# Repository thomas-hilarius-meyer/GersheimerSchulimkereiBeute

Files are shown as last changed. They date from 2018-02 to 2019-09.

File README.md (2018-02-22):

# GersheimerSchulimkereiBeute
Entwicklung eines Bienenkastens für die pädagogisch ausgerichtete Bienenhaltung - LaTeX-Dateien und CAD-Pläne

Es geht um die Entwicklung eines Bienenkastens, der sich in besonderer Weise dazu eignet, das imkern zu lernen:

- Keine schweren Honigzargen heben.
- keine auffliegenden Bienen beim Abheben einer ganzen Etage.
- trotzdem ein ein gängiges Wabenmaß (Zander).
- einfachste Herstellung und
- geringe Kosten.

Mitentwickler herzlich willkommen.

(Zur Bearbeitung der Pläne wird FreeCAD benötigt;
die Texte sind in LATeX erstellt.)

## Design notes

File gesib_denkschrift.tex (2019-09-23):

\documentclass[12pt,a4paper,ngerman]{scrartcl}

\usepackage[ngerman]{babel}
\usepackage[utf8]{inputenc}
\usepackage[T1]{fontenc}
\usepackage{csquotes}
\usepackage{graphicx}
\usepackage{hyperref}

\author{Dr. Thomas Hilarius Meyer\\ \textsf{thomas.hilarius.meyer@gmail.com}}
\title{Die Gersheimer Schulimkerei-Beute (GeSIB)}
\subtitle{Überlegungen zu Konzeption, Bau und Betriebsweise}
\date{Fassung 24. März 2019}

\begin{document}
\maketitle

\begin{abstract}
  Die Gersheimer Schulimkerei-Beute (GeSIB) ist eine Trogbeute für 21 Waben im Zander-Maß.
  Sie eignet sich besonders für den pädagogisch motivierten Umgang mit Bienen, da alle Waben in einer
  Ebene liegen und somit direkt einsehbar und zugänglich sind; im Umgang mit ihr sind
  keine schweren Gewichte zu heben und die Arbeitshöhe bleibt konstant.
  Alle Verfahren der modernen Magazin-Imkerei lassen sich mit der GeSIB durchführen und
  ein späterer Wechsel der Jungimker etwa zu üblichen Magazinbeuten ist problemlos möglich.
\end{abstract}

\section{Gestaltungsprinzipien}

Die Zeit ist reif für einen neuen Bienenkasten,
der speziell auf die Bedürfnisse einer Schulimkerei und ihrer Mitglieder --
besonders in den ersten 1--2 Jahren des Imkern-Lernens -- ausgelegt ist!

Die Mitglieder der Schulimkerei Gersheim haben eine Bienenbeute entwickelt,
die sich ausschließlich diesem Ziel widmet:
die Gersheimer Schulimkerei-Beute (GeSIB).

Nach Abschluss des laufenden Erprobungsbetriebes wird die Herstellung der GeSIB die Angebotspalette unserer
Schülerfirma entscheidend erweitern;
gleichzeitig stehen die Baupläne der Öffentlichkeit zur Verfügung.%
\footnote{\url{http:\\\\github.com\\thomas-hilarius-meyer\\GersheimerSchulimkereiBeute}}

\subsection{Vorüberlegungen / Anforderungen}

Was müsste ein Schulbienenkasten besser können als etablierter und bewährter Bienenkasten,
z.\,B. die \enquote{Liebig-Beute}?

\begin{enumerate}
\item Die Imkerneulinge sollen keine Zargen abheben müssen, denn dies bedeutet\ldots
  \begin{itemize}
  \item eine Frage der Kraft,
  \item ist eine psychologische Hemmschwelle
  \item  und eine Störung der Bienen.
  \end{itemize}
\item Alle Teile des Bienenstocks sollen gleichzeitig sichtbar sein (von oben, auf einen Blick),
\item das Wabenmaß soll das weit verbreitete Zandermaß sein,
  um später leichter auf Magazinbeuten umsteigen zu können (eine Beute, aus der man \enquote{herauswächst}...),
\item die Betriebsweise soll sehr nahe an der Magazinimkerei liegen (imkern lernen) und
\item der Bau soll zu einem geringen Preis und
\item mit wenig Aufwand möglich sein.
\end{enumerate}

In Kauf genommene Nachteile sind weitgehend irrelevant für den speziellen Zweck der \enquote{pädagogischen} Bienenbeute:

\begin{itemize}
\item \enquote{Unwirtschaftliches} Arbeiten (\enquote{wabenweise} statt \enquote{zargenweise}) -- es geht nicht um Erwerbsbienenhaltung,
  sondern um pädagogisch orientiertes Imkern.
\item Schwieriges Wandern wegen des hohen Beuten-Gewichts -- eine Schulimkerei ist erfahrungsgemäß immer eine Standimkerei.
\end{itemize}

\subsection{Konkrete Designentscheidungen}

Folgende Konstruktionsentscheidungen sind für den Entwurf maßgeblich:

\begin{itemize}
\item Zander-Rähmchen als verbreitetstes Rähmchenmaß,
\item gleiches Maß im Brut- und Honigraum,
\item Möglichkeit eines vertikalen Königinnenabsperrgitters und
\item einer vertikalen Bienenflucht,
\item extrem leichter Zusammenbau aus wenigen, einfachen Teilen.
\end{itemize}

\section{Bisherige Ansätze}

Welche Bienenkästen mit grundsätzlich ähnlicher Konstruktion (Waben auf einer Ebene)
gibt es schon und warum sind diese für die speziellen Zwecke einer Schulimkerei
nicht oder nicht optimal geeignet?

\begin{description}
\item[Hohenheimer Einfachbeute] ideales System für \enquote{erwachsene} Imker;
  doch Nachteil: schweres Heben, Scheu des Zargen-Abhebens\ldots
\item[Golzbeute] komplizierter Aufbau, teuer, spezielles Wabenmaß (Kuntzsch hoch), keine Bienenflucht.
\item[Mellifera Einraumbeute] spezielles Wabenmaß, kein Abspergitter und keine Bienenflucht möglich.
\item[Top-Bar-Hive] Umstieg auf Magazin-Imkerei sehr kompliziert.
\item[Bienenkiste] extrem unergonomisch; Stabilbau verhindert Wabenkontrolle.
\item[Kunesa-Beute] extrem hoher Preis; Werkstoff Kunststoff erlaubt kein handwerkliches Arbeiten
  (Reparaturen etc.) und auch keinen Selbstbau.
\item[BienenBox] Seltenes Wabenformat (Format Kuntzsch hoch) macht den Umstieg auf Magazinbeuten schwierig
  (www.bienenbox.de)
\item[Citybox (Fa. Holtermann)] hoher Preis, teilweise überspezielle Features
\item[Alpentrogbeute (V. Weber)] komplizierter Aufbau, schwer zu bekommen, Honigräume werden aufgesetzt --
  dadurch gehen gerade die Vorzüge der Trogbeute verloren!
\end{description}

\section{Bau}

\minisec{Planskizze}

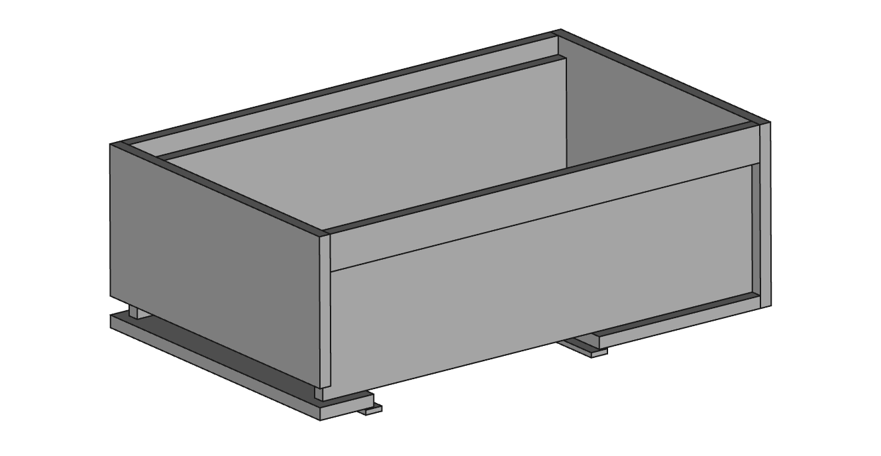
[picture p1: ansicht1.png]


\begin{center}
  [Achtung! Älterer Planungsstand, Skizze nicht maßstabsgerecht!
  Vgl. ggf. separate FreeCAD-Datei bzw. PDF-Pläne für konstruktive Details.]
\end{center}

\minisec{Teileliste}

\begin{center}
\begin{tabular}{lll}
  Bezeichnung &                       Maße [in mm] &          Anzahl \\
  \hline
  Leimholzplatten 25mm: \\
  Seitenbrett links + rechts &        800 x 270 &             2 \\
  Seitl. Griffbrett links + rechts &  800 x 60 &              2 \\
  Stirnbrett vorne &                  540 x 275 &             1 \\
  Rückwand &                          540 x 320 &             1 \\
  Bodenbrett hinten &                 540 x 360 &             1 \\
  Bodenbrett vorne &                  540 x 100 &             1 \\
  \hline
  Sperrholz 8mm o.\,ä.: \\
  Schubleisten &                      540 x 60 &              2 \\
  \hline
  Dämmmaterial (z.\,B. MDF): \\
  Innendeckel (Dämmmaterial) &        850 x 540 &             1 \\
  \hline
\end{tabular}
\end{center}

Alternativ zum MDF-Innendeckel lassen sich auch zwei Standard-Liebig-Innendeckel nebeneinander verwenden.

\minisec{Zusatzteile}

\begin{center}
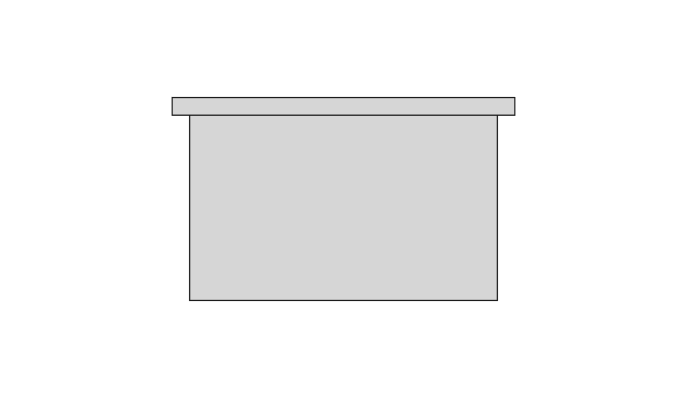
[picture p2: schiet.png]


\begin{tabular}{ll}
  Bezeichnung &                       Maße [in mm] \\
  \hline
  Trägerleiste &                      490 x 25 x 10 \\
  Schiet-Brett &                      440 x 295 x 10 \\
  \hline
\end{tabular}
\end{center}

Zum Betrieb werden drei Varianten eines vertikalen Trennschieds benötigt:

\begin{itemize}
\item das Trennschied selbst, um v.\,a. im Winter den Innenraum der Beute zu begrenzen,
\item ein vertikales Königinnenabsperrgitter und
\item eine vertikale Bienenflucht.
\end{itemize}

\minisec{Zusätzliches Material}

\begin{itemize}
\item Schrauben 5x60mm
\item wasserfester Leim
\item Anstrich (Leinölfirnis)
\end{itemize}

\section{Offene Fragen}

Folgende Punkte sollen während des derzeit (2019/20) laufenden ersten Jahres Erprobungsbetrieb untersucht werden,
um ggf. die Konstruktion noch zu verändern:

\begin{enumerate}
%\item Boden: Öffnungen wegen Belüftung und besserer Varroabeobachtung? Oder reicht die Zugänglichkeit über das Flugloch?
%  (Stabilität der Konstruktion)
\item Notwendigkeit des Abspergitters:
  evtl. unnötig wg. des natürlichen Triebs der Königin, das Brutnest fluglochnah zusammenzuhalten?
\item Effektivität der vertikalen Bienenflucht?
\end{enumerate}

\section{Betriebsweise}

Die imkerliche Betriebsweise mit der GSIB ähnelt grundsätzlich sehr stark den Verfahrensweisen in der Magazin-Imkerei (Liebig 2011):

\subsection{Varroa: Winterbehandlung mit Oxalsäure}

Die Bekämpfung der Varroamilbe im brutfreien Zustand im Winter kann problemlos sowohl durch Träufeln von oben als auch durch Verdampfen von unten erfolgen.
Durch die flache Bauweise wird der Bienensitz nur minimal gestört.

%(Idee: Einblasloch im Fluglochstück? Entwicklung eines Verdampfers auf Basis eines Gasbrenners?)

\subsection{Ablegerbildung}

Die Vermehrung der Völkerzahl durch die Bildung von Ablegern erfolgt
entweder durch Bildung in der GeSIB (mit Fluglochverkleinerung und Volumenbegrenzungsschied)
oder in normalem Zander-Ablegerkasten (gleiches Wabenmaß).

\subsection{Honigernte}

Durch die Benutzung des vertikalen Absperrgitters sowie
der vertikale Bienenflucht
gestaltet sich die Honigernte einfach und ohne massiv mit den Bienen in Kontakt zu kommen.

\subsection{Varroa: Sommerbehandlung mit Ameisensäure}

Die Sommerbehandlung der Varroamilbe erfolgt am einfachsten durch Einsatz der bekannten
Nassenheider Professional-Verdunster im bisherigen Honigraum.

Die Bodenöffnung lässt sich mit Bodenschiebern der standardisierten Liebig-Beute verschließen.

\subsection{Einfütterung}

Der Futtereimer findet ebenfalls problemlos im Honigraum Platz.

\subsection{Überwinterung}

Zur Erhaltung des Stockklimas ist der Einsatz des Trennschiedes während des Winters notwendig, das eng an die besetzten Waben herangerückt wird.
Die thermischen Eigenschaften der GeSIB sind dann nicht ungünstiger als bei einer Magazinbeute.

\section{Chronologie}

\begin{description}
\item[Herbst 2017] erste Vorüberlegungen
\item[Januar/Februar 2018] Planskizze
\item[Winter 2018/19] Bau eines Prototypen; Überarbeitung der Maße
\item[Imkersaison 2019/20] Erprobungsbetrieb in Gersheim
\end{description}

\section{Literaturhinweise}

\begin{enumerate}
\item Johannes Otto Hüsing u. Joachim Nitschmann (Hgg.), Lexikon der Bienenkunde, München 1987; s.\,v.
  \enquote{Trogbeute} u.
  \enquote{Entwicklung der Bienenwohnungen.}
\item Gerhard Liebig, Einfach imkern, (3. Aufl.) 2011.
\item Friedrich Pohl (Hg.), Bienenkiste, Korb und Einfachbeuten. Naturnah und erfolgreich imkern, Stuttgart 2013.
\item Johannes Weber, Bienen halten mit der BienenBox, Stuttgart 2016.
\item Vinzenz Weber, Leichter imkern mit Trogbeuten, München (2. Aufl.) 1990.
\end{enumerate}

\section{Ressourcen}

\url{http:\\\\schulimkerei.blogspot.com}

\url{http:\\\\github.com\\thomas-hilarius-meyer\\GersheimerSchulimkereiBeute}

\end{document}

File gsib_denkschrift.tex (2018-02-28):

\documentclass[12pt,a4paper,ngerman]{scrartcl}

\usepackage[ngerman]{babel}
\usepackage[utf8]{inputenc}
\usepackage[T1]{fontenc}
\usepackage{csquotes}
\usepackage{graphicx}

\author{Thomas Hilarius Meyer\\ \textsf{thomas.hilarius.meyer@gmail.com}}
\title{Die Gersheimer Schulimkerei-Beute (GSIB)}
\subtitle{Überlegungen zu Konzeption, Bau und Betriebsweise}

\begin{document}
	\maketitle

\begin{abstract}
	Die Gersheimer Schulimkerei-Beute (GSIB) ist eine Trogbeute für 24 Zander-Rähmchen.
	Sie eignet sich besonders für den pädagogischen Umgang mit Bienen, da alle Waben in einer
	Ebene liegen und somit direkt einsehbar und zugänglich sind; im Umgang mit ihr sind
	keine schweren Gewichte zu heben und die Arbeitshöhe bleibt konstant.
	Alle Verfahren der modernen Magazin-Imkerei lassen sich mit der GSIB durchführen und
	ein späterer Wechsel der Jungimker etwa zur Liebigbeute ist problemlos möglich.
\end{abstract}

\section{Gestaltungsprinzipien}

Die Zeit ist reif für einen neuen Bienenkasten, der speziell auf die Bedürfnisse einer Schulimkerei und ihrer Mitglieder --
besonders in den ersten 1--2 Jahren des Imkern-Lernens -- ausgelegt ist!

Die Mitglieder der Schulimkerei Gersheim haben eine Bienenbeute entwickelt, die sich ausschließlich diesem Ziel widmet:
die Gersheimer Schulimkerei-Beute (GSIB).

Nach einem angemessenen Erprobungsbetrieb könnte die Herstellung der GSIB die Angebotspalette unserer Schüllerfirma
entscheidend erweitern.

\subsection{Vorüberlegungen / Anforderungen}

Was müsste ein Schulbienenkasten besser können als die Liebig-Beute?

\begin{enumerate}
\item Die Imkerneulinge sollen keine Zargen abheben müssen, denn dies bedeutet...
  \begin{itemize}
  \item eine Frage der Kraft,
  \item ist eine psychologische Hemmschwelle
  \item  und eine Störung der Bienen.
  \end{itemize}
\item Alle Teile des Bienenstocks sollen gleichzeitig sichtbar sein (von oben, auf einen Blick),
\item das Wabenmaß soll das weit verbreitete Zandermaß sein,
  um später leichter auf Magazinbeuten umsteigen zu können (eine Beute, aus der man \enquote{herauswächst}...),
\item die Betriebsweise soll sehr nahe an der Magazinimkerei liegen (imkern lernen) und
\item der Bau soll zu einem geringen Preis und
\item mit wenig Aufwand möglich sein.
\end{enumerate}

In Kauf genommene Nachteile sind weitgehend irrelevant für den speziellen Zweck der \enquote{pädagogischen} Bienenbeute:

\begin{itemize}
\item \enquote{Unwirtschaftliches} Arbeiten (\enquote{wabenweise} statt \enquote{zargenweise}) -- es geht nicht um Erwerbsbienenhaltung,
  sondern um pädagogisch orientiertes Imkern.
\item Schwieriges Wandern wegen des hohen Beuten-Gewichts -- eine Schulimkerei ist erfahrungsgemäß immer eine Standimkerei.
\end{itemize}

\subsection{Konkrete Designentscheidungen}

Folgende Konstruktionsentscheidungen sind für den Entwurf maßgeblich:

\begin{itemize}
\item Zander-Rähmchen als verbreitetstes Rähmchenmaß,
\item gleiches Maß im Brut- und Honigraum,
\item vertikales Königinnenabsperrgitter möglich,
\item Möglichkeit einer vertikalen Bienenflucht,
\item extrem leichter Zusammenbau aus wenigen, einfachen Teilen.
\end{itemize}

\section{Bisherige Ansätze}

Welche Bienenkästen mit grundsätzlich ähnlicher Konstruktion (Waben auf einer Ebene) gibt es schon und warum sind diese
für die speziellen Zwecke einer Schulimkerei nicht oder nicht optimal geeignet?

\begin{description}
\item[Hohenheimer Einfachbeute] ideales System für \enquote{erwachsene} Imker; doch Nachteil: schweres Heben, Scheu des Zargen-Abhebens...
\item[Golzbeute] komplizierter Aufbau, teuer, spezielles Wabenmaß (Kuntzsch hoch), keine Bienenflucht.
\item[Mellifera Einraumbeute] spezielles Wabenmaß, kein Abspergitter und keine Bienenflucht möglich.
\item[Top-Bar-Hive] Umstieg auf Magazin-Imkerei sehr kompliziert.
\item[Bienenkiste] extrem unergonomisch; Stabilbau verhindert Wabenkontrolle.
\item[Kunesa-Beute]
\item[BienenBox] Format Kuntzsch (hoch)  (www.bienenbox.de)
\item[Citybox (Fa. Holtermann)]
\item[Alpentrogbeute (V. Weber)] komplizierter Aufbau, schwer zu bekommen, Honigräume werden aufgesetzt!
\end{description}

\section{Bau}



[vgl. separate FreeCAD-Datei bzw. PDF-Pläne für konstruktive Details.]

\minisec{Teileliste}

\begin{center}
\begin{tabular}{lll}
  Bezeichnung &                       Maße [in mm] &          Anzahl \\
  \hline
  Seitenbrett links + rechts &        800 x 240 &             2 \\
  Seitl. Griffbrett links + rechts &  800 x 60 &              2 \\
  Stirnbrett vorne &                  540 x 240 &             1 \\
  Rückwand &                          540 x 290 &             1 \\
  Bodenbrett hinten &                 540 x 300 &             1 \\
  Bodenbrett vorne &                  540 x 100 &             1 \\
  Schubleisten &                      540 x 30 x 8 &          2 \\
  \hline
  Innendeckel (Dämmmaterial) &        850 x 540 &             1 \\
  \hline
\end{tabular}

[Materialstärke 25mm wenn nicht angegeben.]
\end{center}

\minisec{Zusatzteile}

\begin{itemize}
\item vertikales Königinnenabsperrgitter
\item vertikale Bienenflucht
\end{itemize}

\section{Offene Fragen}

\begin{enumerate}
%\item Boden: Öffnungen wegen Belüftung und besserer Varroabeobachtung? Oder reicht die Zugänglichkeit über das Flugloch?
%  (Stabilität der Konstruktion)
\item Notwendigkeit des Abspergitters: evtl. unnötig wg. des natürlichen Triebs der Königin, das Brutnest fluglochnah zusammenzuhalten?
\end{enumerate}

\section{Betriebsweise}

\subsection{Varroa: Winterbehandlung mit Oxalsäureverdampfer}

(Idee: Einblasloch im Fluglochstück? Entwicklung eines Verdampfers auf Basis eines Gasbrenners?)

\subsection{Ablegerbildung}

Entweder Bildung in der GSB (mit Fluglochverkleinerung und Volumenbegrenzungsschied)
oder in normalem Zander-Ablegerkasten

\subsection{Honigernte}

Benutzung des vertikalen Absperrgitters

vertikale Bienenflucht

\subsection{Varroa: Sommerbehandlung mit Ameisensäure}

Nassenheider Professional im bisherigen Honigraum

\subsection{Einfütterung}

Eimer im Honigraum

\section{Chronologie}

\begin{description}
\item[Herbst 2017] erste Vorüberlegungen
\item[Januar/Februar 2018] Planskizze
\item[Imkersaison 2018] Erprobungsbetrieb in Gersheim
\end{description}

\section{Literaturhinweise}

\begin{enumerate}
\item Gerhard Liebig, Einfach imkern, (3. Aufl.) 2011.
\item Friedrich Pohl (Hg.), Bienenkiste, Korb und Einfachbeuten. Naturnah und erfolgreich imkern, Stuttgart 2013.
\item Johannes Weber, Bienen halten mit der BienenBox, Stuttgart 2016.
\item Vinzenz Weber, Leichter imkern mit Trogbeuten, München (2. Aufl.) 1990.
\end{enumerate}
\end{document}

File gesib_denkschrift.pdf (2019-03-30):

# Die Gersheimer Schulimkerei-Beute (GeSIB)

### Überlegungen zu Konzeption, Bau und Betriebsweise

## Thomas Hilarius Meyer

## thomas.hilarius.meyer@gmail.com

## 1. März 2019

Die Gersheimer Schulimkerei-Beute (GeSIB) ist eine Trogbeute für 21 Waben im Zander-Maß. Sie eignet sich besonders für den pädagogisch motivierten Umgang mit Bienen, da alle Waben in einer Ebene liegen und somit direkt einsehbar und zugänglich sind; im Umgang mit ihr sind keine schweren Gewichte zu heben und die Arbeitshöhe bleibt konstant. Alle Verfahren der modernen Magazin-Imkerei lassen sich mit der GeSIB durchführen und ein späterer Wechsel der Jungimker etwa zu üblichen Magazinbeuten ist problemlos möglich.

## 1 Gestaltungsprinzipien

Die Zeit ist reif für einen neuen Bienenkasten, der speziell auf die Bedürfnisse einer Schulimkerei und ihrer Mitglieder – besonders in den ersten 1–2 Jahren des Imkern-Lernens – ausgelegt ist!
Die Mitglieder der Schulimkerei Gersheim haben eine Bienenbeute entwickelt, die sich ausschließlich diesem Ziel widmet: die Gersheimer Schulimkerei-Beute (GeSIB).
Nach einem angemessenen Erprobungsbetrieb könnte die Herstellung der GeSIB die Angebotspalette unserer Schülerfirma entscheidend erweitern.

### 1.1 Vorüberlegungen / Anforderungen

Was müsste ein Schulbienenkasten besser können als die Liebig-Beute?

1. Die Imkerneulinge sollen keine Zargen abheben müssen, denn dies bedeutet...
- eine Frage der Kraft,
- ist eine psychologische Hemmschwelle

1

- und eine Störung der Bienen.
2. Alle Teile des Bienenstocks sollen gleichzeitig sichtbar sein (von oben, auf einen Blick),
3. das Wabenmaß soll das weit verbreitete Zandermaß sein, um später leichter auf Magazinbeuten umsteigen zu können (eine Beute, aus der man „herauswächst“...),
4. die Betriebsweise soll sehr nahe an der Magazinimkerei liegen (imkern lernen) und
5. der Bau soll zu einem geringen Preis und
6. mit wenig Aufwand möglich sein.

In Kauf genommene Nachteile sind weitgehend irrelevant für den speziellen Zweck der „pädagogischen“ Bienenbeute:

- „Unwirtschaftliches“ Arbeiten („wabenweise“ statt „zargenweise“) – es geht nicht um Erwerbsbienenhaltung, sondern um pädagogisch orientiertes Imkern.
- Schwieriges Wandern wegen des hohen Beuten-Gewichts – eine Schulimkerei ist erfahrungsgemäß immer eine Standimkerei.

### 1.2 Konkrete Designentscheidungen

Folgende Konstruktionsentscheidungen sind für den Entwurf maßgeblich:

- Zander-Rähmchen als verbreitetstes Rähmchenmaß,
- gleiches Maß im Brut- und Honigraum,
- Möglichkeit eines vertikalen Königinnenabsperrgitters und
- einer vertikalen Bienenflucht,
- extrem leichter Zusammenbau aus wenigen, einfachen Teilen.

## 2 Bisherige Ansätze

Welche Bienenkästen mit grundsätzlich ähnlicher Konstruktion (Waben auf einer Ebene) gibt es schon und warum sind diese für die speziellen Zwecke einer Schulimkerei nicht oder nicht optimal geeignet?

Hohenheimer Einfachbeute ideales System für „erwachsene“ Imker; doch Nachteil: schweres Heben, Scheu des Zargen-Abhebens...

Golzbeute komplizierter Aufbau, teuer, spezielles Wabenmaß (Kuntzsch hoch), keine Bienenflucht.

2

Mellifera Einraumbeute spezielles Wabenmaß, kein Abspergitter und keine Bienenflucht möglich.

Top-Bar-Hive Umstieg auf Magazin-Imkerei sehr kompliziert.

Bienenkiste extrem unergonomisch; Stabilbau verhindert Wabenkontrolle.

Kunesa-Beute extrem hoher Preis; Werkstoff Kunststoff erlaubt kein handwerkliches Arbeiten (Reparaturen etc.).

BienenBox Seltenes Wabenformat (Format Kuntzsch hoch) macht den Umstieg auf Magazinbeuten schwierig (www.bienenbox.de)

Citybox (Fa. Holtermann) hoher Preis, teilweise überspezielle Features

Alpentrogbeute (V. Weber) komplizierter Aufbau, schwer zu bekommen, Honigräume werden aufgesetzt – dadurch gehen gerade die Vorzüge der Trogbeute verloren!

## 3 Bau

Planskizze

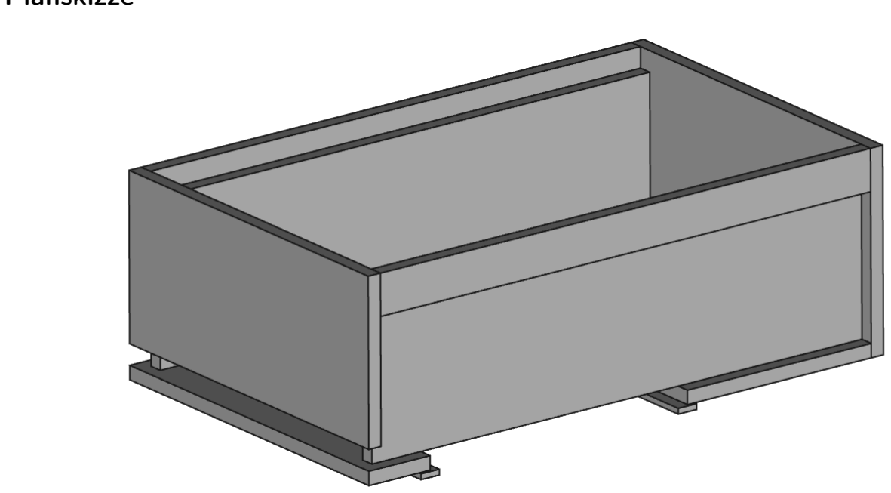
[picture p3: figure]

[Achtung! Älterer Planungsstand, Skizze nicht maßstabsgerecht! Vgl. ggf. separate FreeCAD-Datei bzw. PDF-Pläne für konstruktive Details.]

3

Teileliste
Bezeichnung | Maße [in mm] Anzahl
Leimholzplatten 25mm:
Seitenbrett links + rechts | 800 x 270 | 2
Seitl. Griffbrett links + rechts 800 x 60 | 2
Stirnbrett vorne | 540 x 275 | 1
Rückwand | 540 x 320 | 1
Bodenbrett hinten | 540 x 360 | 1
Bodenbrett vorne | 540 x 100 | 1
Sperrholz 8mm o. ä.:
Schubleisten | 540 x 60 | 2
Dämmmaterial (z. B. MDF):
Innendeckel (Dämmmaterial) | 850 x 540 | 1

Alternativ zum MDF-Innendeckel lassen sich auch zwei Standard-Liebig-Innendeckel nebeneinander verwenden.

Zusatzteile


Bezeichnung Maße [in mm]
Trägerleiste | 490 x 25 x 10
Schiet-Brett | 440 x 295 x 10

Zum Betrieb werden drei Varianten eines vertikalen Trennschieds benötigt:

- das Trennschied selbst, um v. a. im Winter den Innenraum der Beute zu begrenzen,
- ein vertikales Königinnenabsperrgitter und
- eine vertikale Bienenflucht.

Zusätzliches Material
- Schrauben 5x60mm
- wasserfester Leim
- Anstrich (Leinölfirnis)

4

## 4 Offene Fragen

Folgende Punkte sollen während des ersten Jahres Erprobungsbetrieb untersucht werden, um ggf. die Konstruktion noch zu verändern:

1. Notwendigkeit des Abspergitters: evtl. unnötig wg. des natürlichen Triebs der Königin, das Brutnest fluglochnah zusammenzuhalten?
2. Effektivität der vertikalen Bienenflucht?

## 5 Betriebsweise

Die imkerliche Betriebsweise mit der GSIB ähnelt grundsätzlich sehr stark den Verfahrensweisen in der Magazin-Imkerei (Liebig 2011):

### 5.1 Varroa: Winterbehandlung mit Oxalsäure

Die Bekämpfung der Varroamilbe im brutfreien Zustand im Winter kann problemlos sowohl durch Träufeln von oben als auch durch Verdampfen von unten erfolgen. Durch die flache Bauweise wird der Bienensitz nur minimal gestört.

### 5.2 Ablegerbildung

Die Vermehrung der Völkerzahl durch die Bildung von Ablegern erfolgt entweder durch Bildung in der GeSIB (mit Fluglochverkleinerung und Volumenbegrenzungsschied) oder in normalem Zander-Ablegerkasten (gleiches Wabenmaß).

### 5.3 Honigernte

Durch die Benutzung des vertikalen Absperrgitters sowie der vertikale Bienenflucht gestaltet sich die Honigernte einfach und ohne massiv mit den Bienen in Kontakt zu kommen.

### 5.4 Varroa: Sommerbehandlung mit Ameisensäure

Die Sommerbehandlung der Varroamilbe erfolgt am einfachsten durch Einsatz der bekannten Nassenheider Professional-Verdunster im bisherigen Honigraum.
Die Bodenöffnung lässt sich mit Bodenschiebern der standardisierten Liebig-Beute verschließen.

### 5.5 Einfütterung

Der Futtereimer findet ebenfalls problemlos im Honigraum Platz.

5

### 5.6 Überwinterung

Zur Erhaltung des Stockklimas ist der Einsatz des Trennschiedes während des Winters notwendig, das eng an die besetzten Waben herangerückt wird. Die thermischen Eigenschaften der GeSIB sind dann nicht ungünstiger als bei einer Magazinbeute.

## 6 Chronologie

Herbst 2017 erste Vorüberlegungen

Januar/Februar 2018 Planskizze

Winter 2018/19 Bau eines Prototypen; Überarbeitung der Maße

Imkersaison 2019 Erprobungsbetrieb in Gersheim

## 7 Literaturhinweise

1. Johannes Otto Hüsing u. Joachim Nitschmann (Hgg.), Lexikon der Bienenkunde, München 1987; s. v. „Trogbeute“ u. „Entwicklung der Bienenwohnungen.“
2. Gerhard Liebig, Einfach imkern, (3. Aufl.) 2011.
3. Friedrich Pohl (Hg.), Bienenkiste, Korb und Einfachbeuten. Naturnah und erfolgreich imkern, Stuttgart 2013.
4. Johannes Weber, Bienen halten mit der BienenBox, Stuttgart 2016.
5. Vinzenz Weber, Leichter imkern mit Trogbeuten, München (2. Aufl.) 1990.

## 8 Ressourcen

http:\\schulimkerei.blogspot.com http:\\github.com\thomas-hilarius-meyer\GersheimerSchulimkereiBeute

6

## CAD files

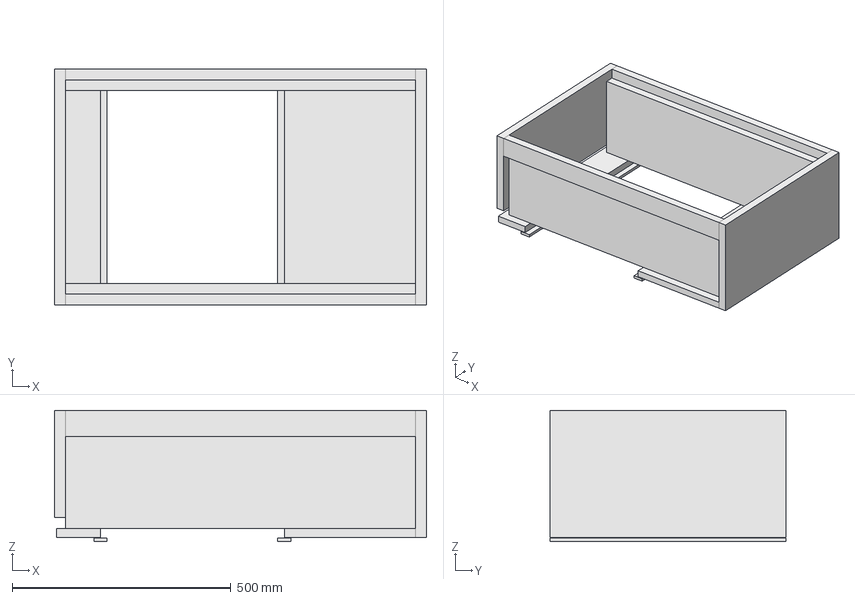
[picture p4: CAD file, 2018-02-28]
Gersheimer_Schulimkerei_Beute_25mm.FCStd
850.0 x 540.0 x 300.0 mm

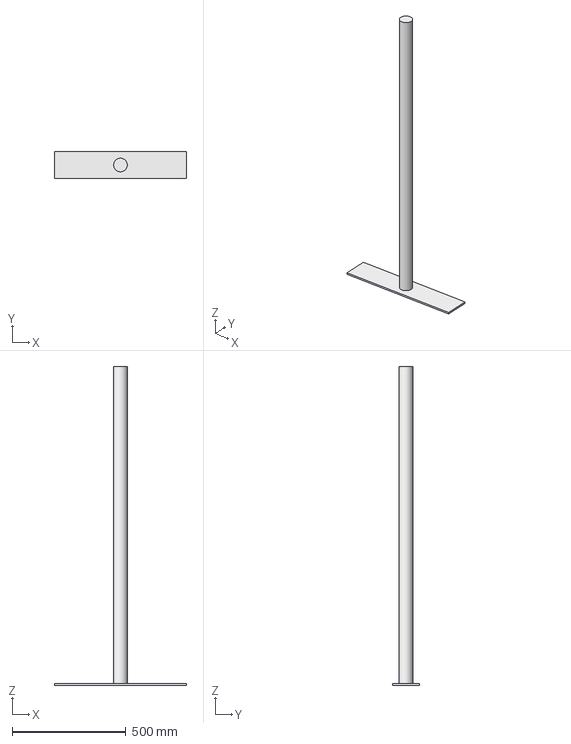
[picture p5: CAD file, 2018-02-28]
Schaukastenpfosten.fcstd
580.0 x 120.0 x 1400.0 mm

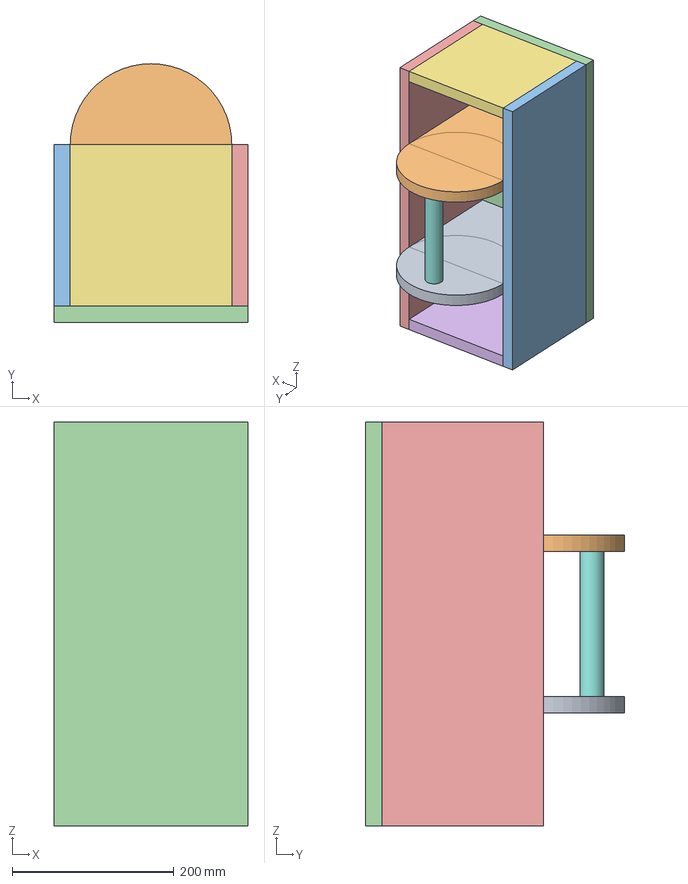
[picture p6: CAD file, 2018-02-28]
Werkzeugkasten.fcstd
240.0 x 320.0 x 500.0 mm
Tragebrett_1
Tragebrett_2
Seitenwand_vorne
Boden
Seitenwand_hinten
Wand_links
Wand_rechts
Griff

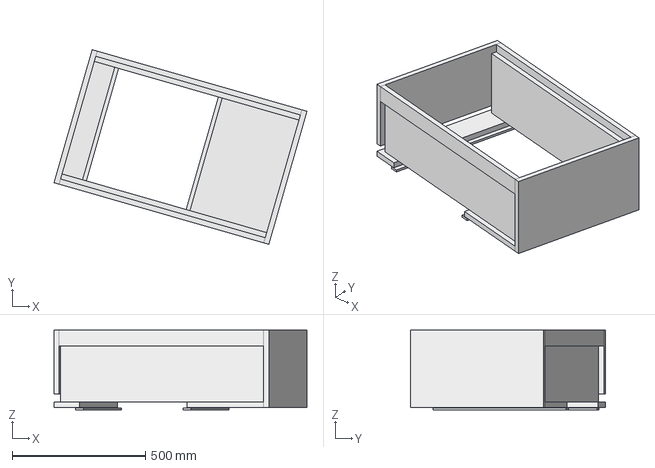
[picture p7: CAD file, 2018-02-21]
Gersheimer_Schulimkerei_Beute_1.FCStd
950.8 x 731.4 x 300.0 mm

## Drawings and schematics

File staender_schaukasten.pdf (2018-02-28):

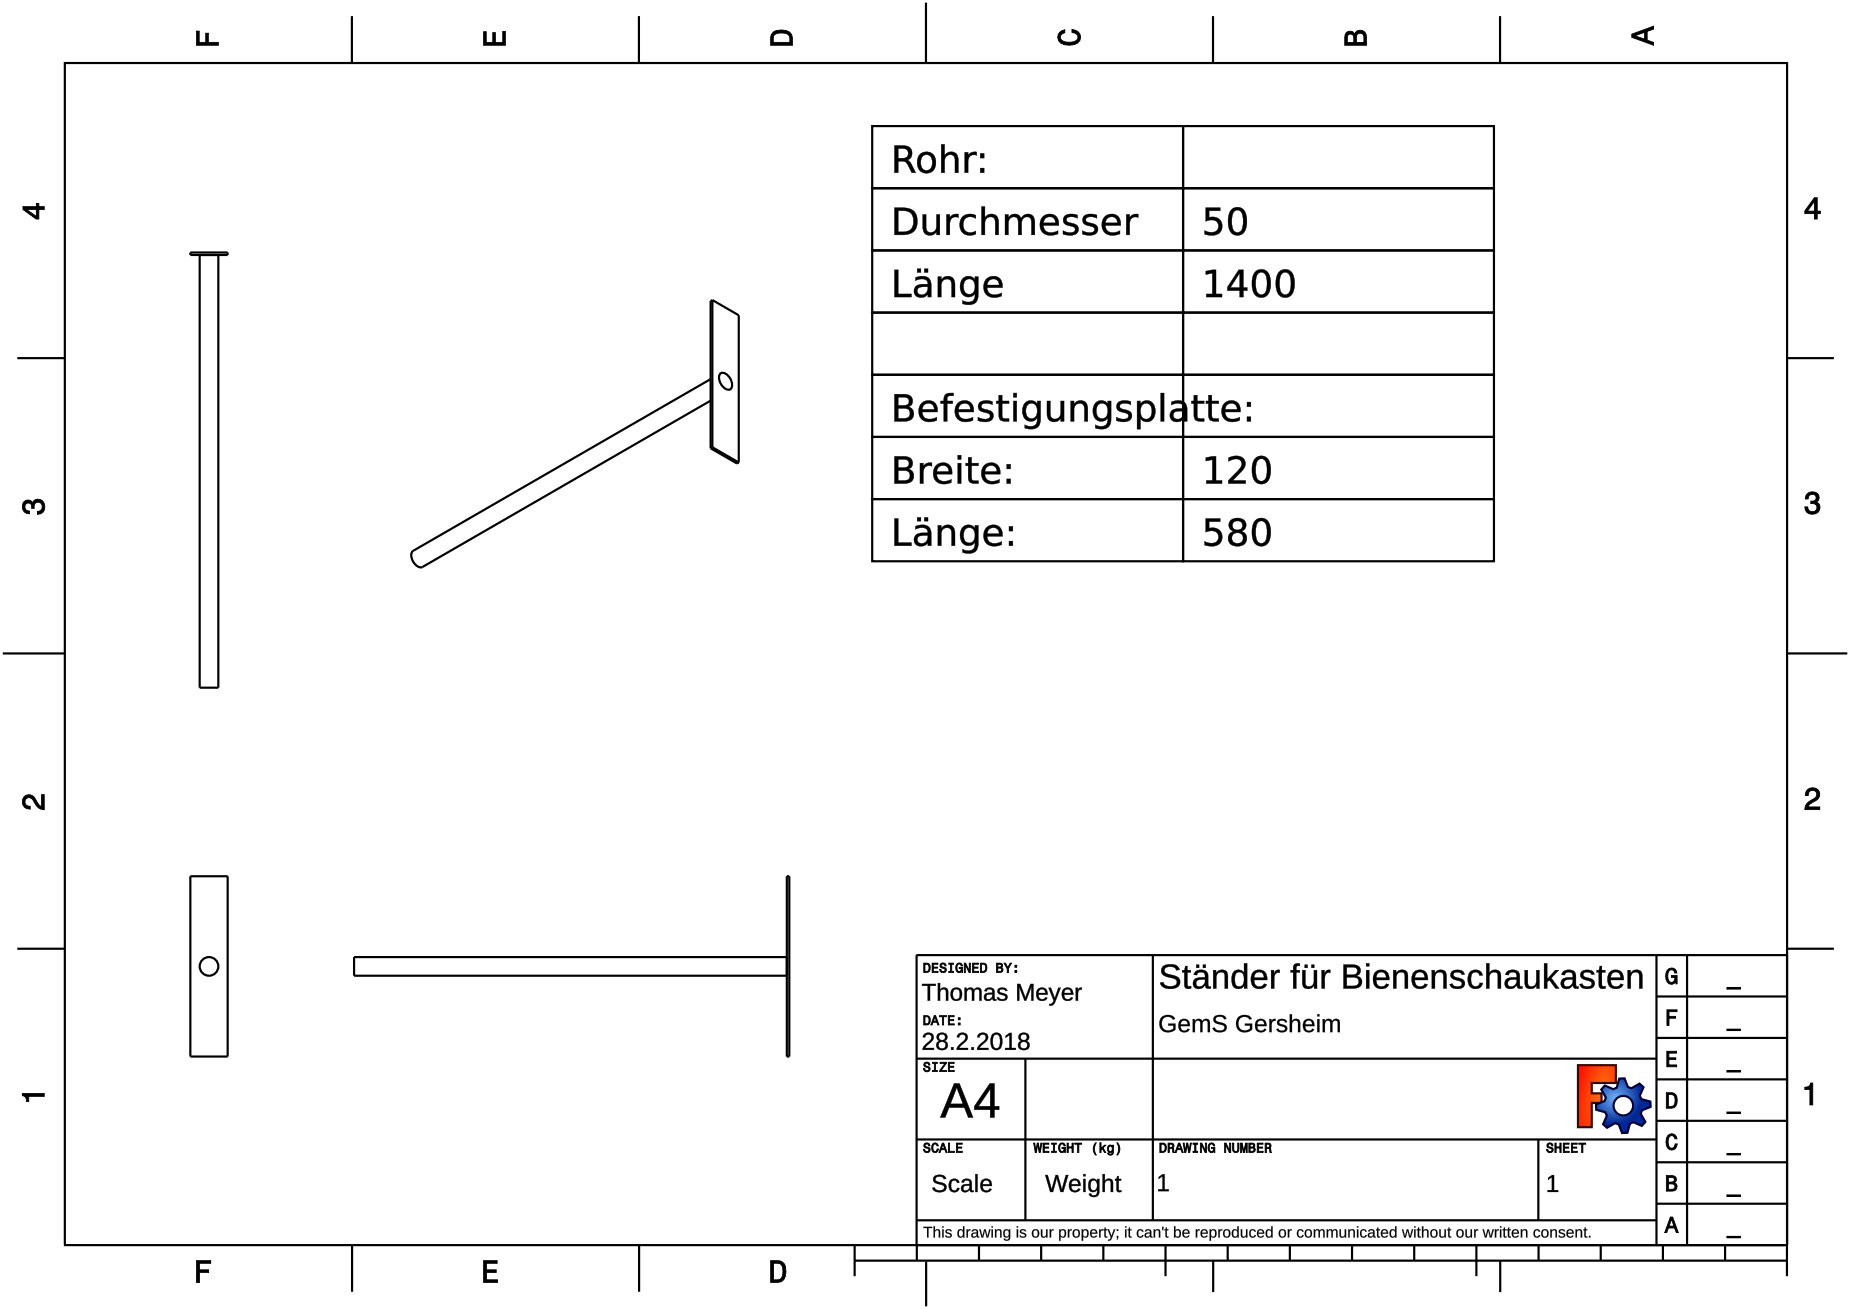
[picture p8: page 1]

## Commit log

2018-02-20 Boden überarbeitet, mit Schaukastenständer
    [Gersheimer_Schulimkerei_Beute_1.FCStd, Schaukastenpfosten.fcstd]
2018-02-22 Beute mit 25mm Wandstärke
    [Gersheimer_Schulimkerei_Beute_25mm.FCStd]
2018-02-28 mit Werkzeugkasten, 25mm Material
    [Werkzeugkasten.fcstd]
2018-02-28 Staender mit besseren Maßen
    [Schaukastenpfosten.fcstd]
2018-02-28 aus GSIB wird GeSIB
    [Gersheimer_Schulimkerei_Beute_25mm.FCStd]
2019-03-30 Masse ueberarbeitet (3cm höher)
